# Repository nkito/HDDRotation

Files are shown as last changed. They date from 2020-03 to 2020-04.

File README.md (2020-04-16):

# HDDRotation - illumination utilizing HDD rotation.

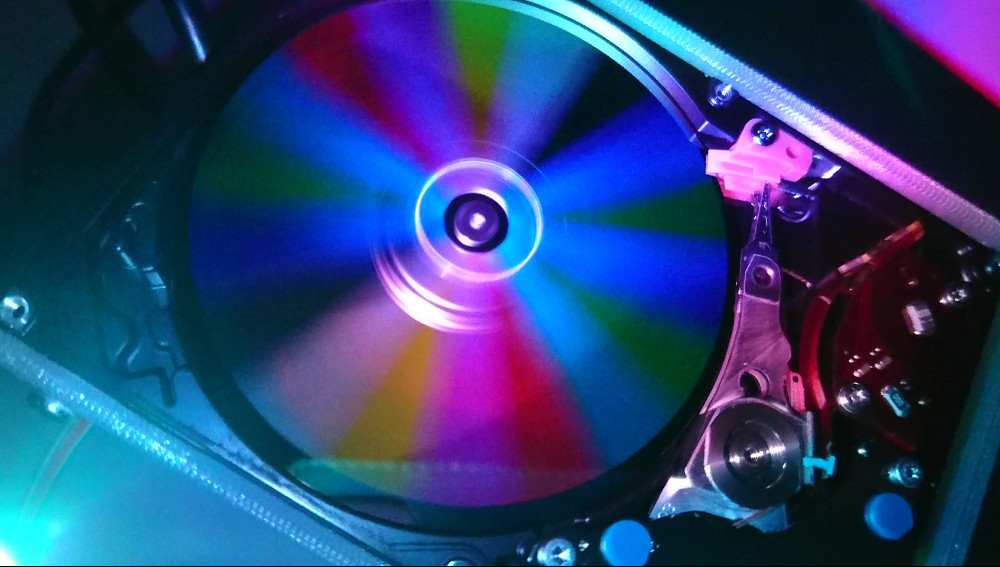
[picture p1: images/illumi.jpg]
illumination


## Overview

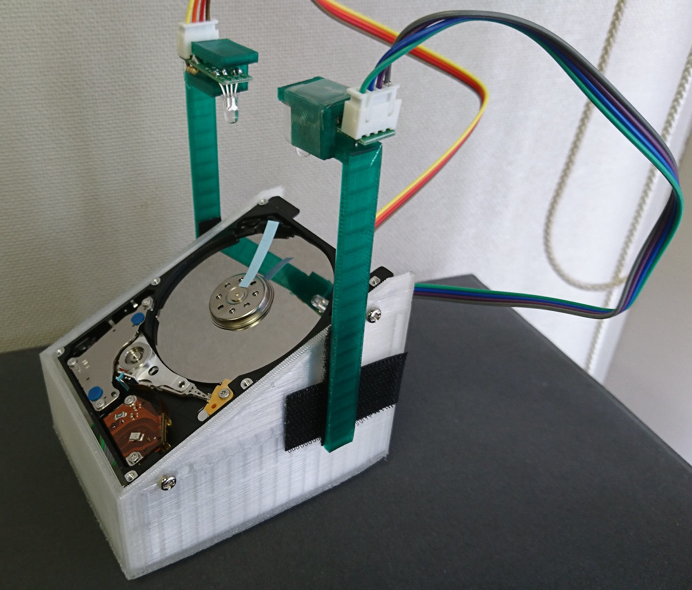
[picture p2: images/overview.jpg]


## Operating principle

The light from the LEDs illuminates the strip of post-it.
The rotation of the strip and the light from the LEDs are synchronized.
In other words, the color of the LEDs varies depending on the position of the strip.
Stable images are observed due to the characteristics of the human eye.

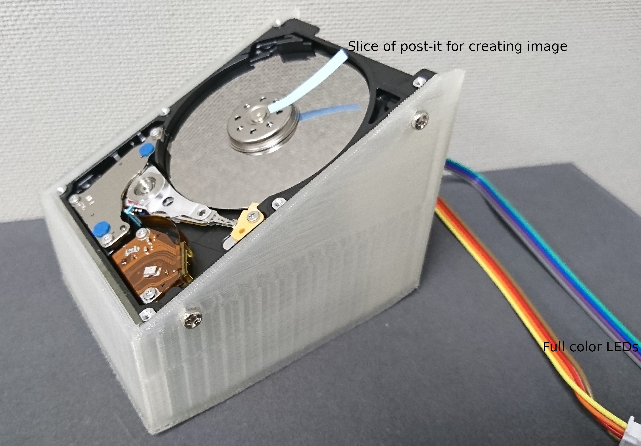
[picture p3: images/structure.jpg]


## Hardware

### Parts

* 2.5-inch HDD
* Arduino Uno
* Transistor Array 2003A (such as TD62003APG(Toshiba), ULN2003AN(TI))
* Full color LEDs
* Some resistors
* Case printed out with a 3D printer
* Screws (M3)

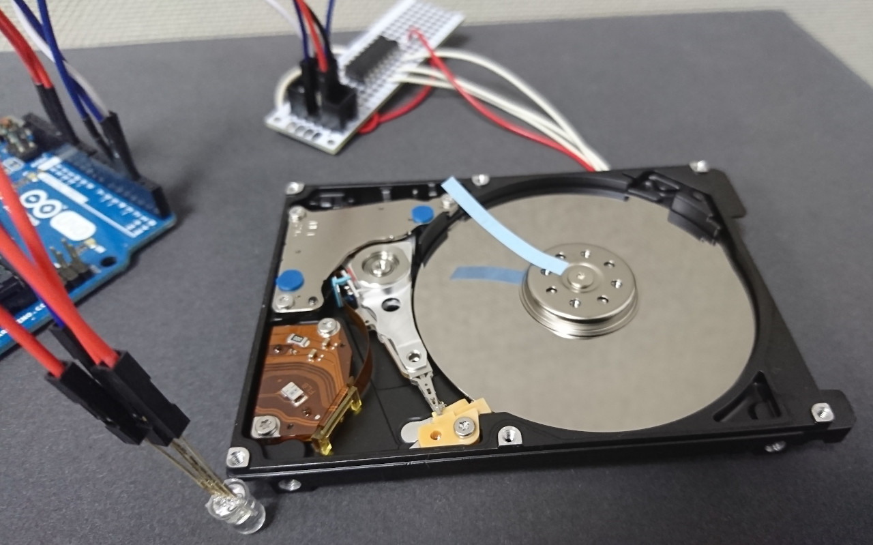
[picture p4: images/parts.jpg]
parts


### Schematic 

Schematic 

### Case

Case

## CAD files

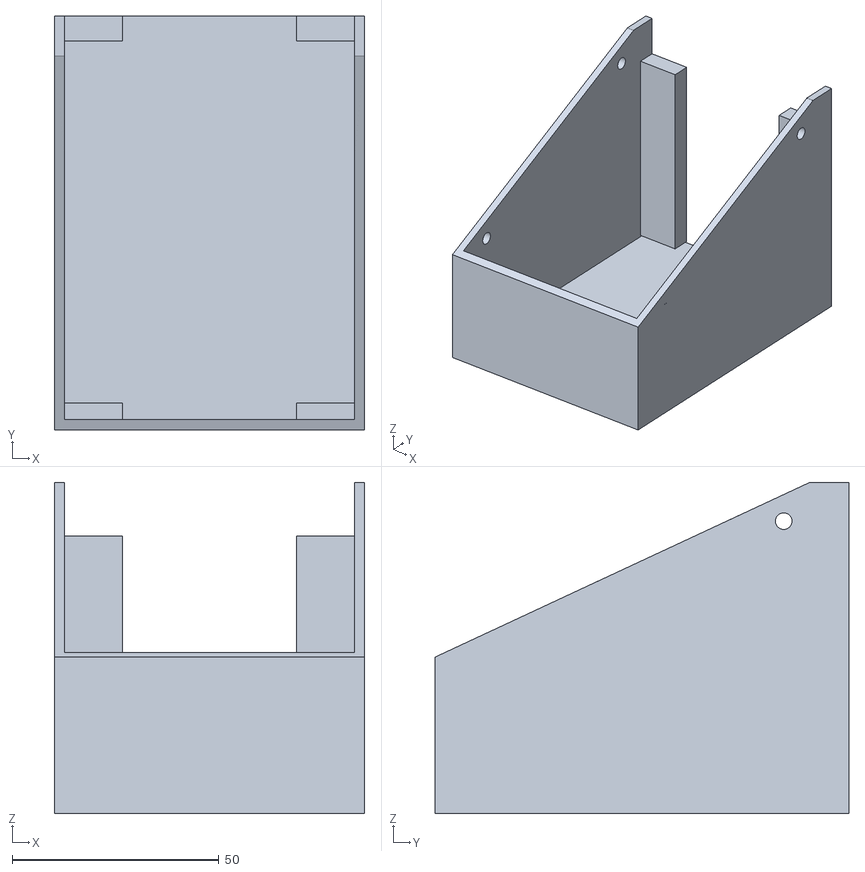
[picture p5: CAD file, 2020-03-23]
3DModel/HDDcase.stl
75.0 x 100.0 x 80.0

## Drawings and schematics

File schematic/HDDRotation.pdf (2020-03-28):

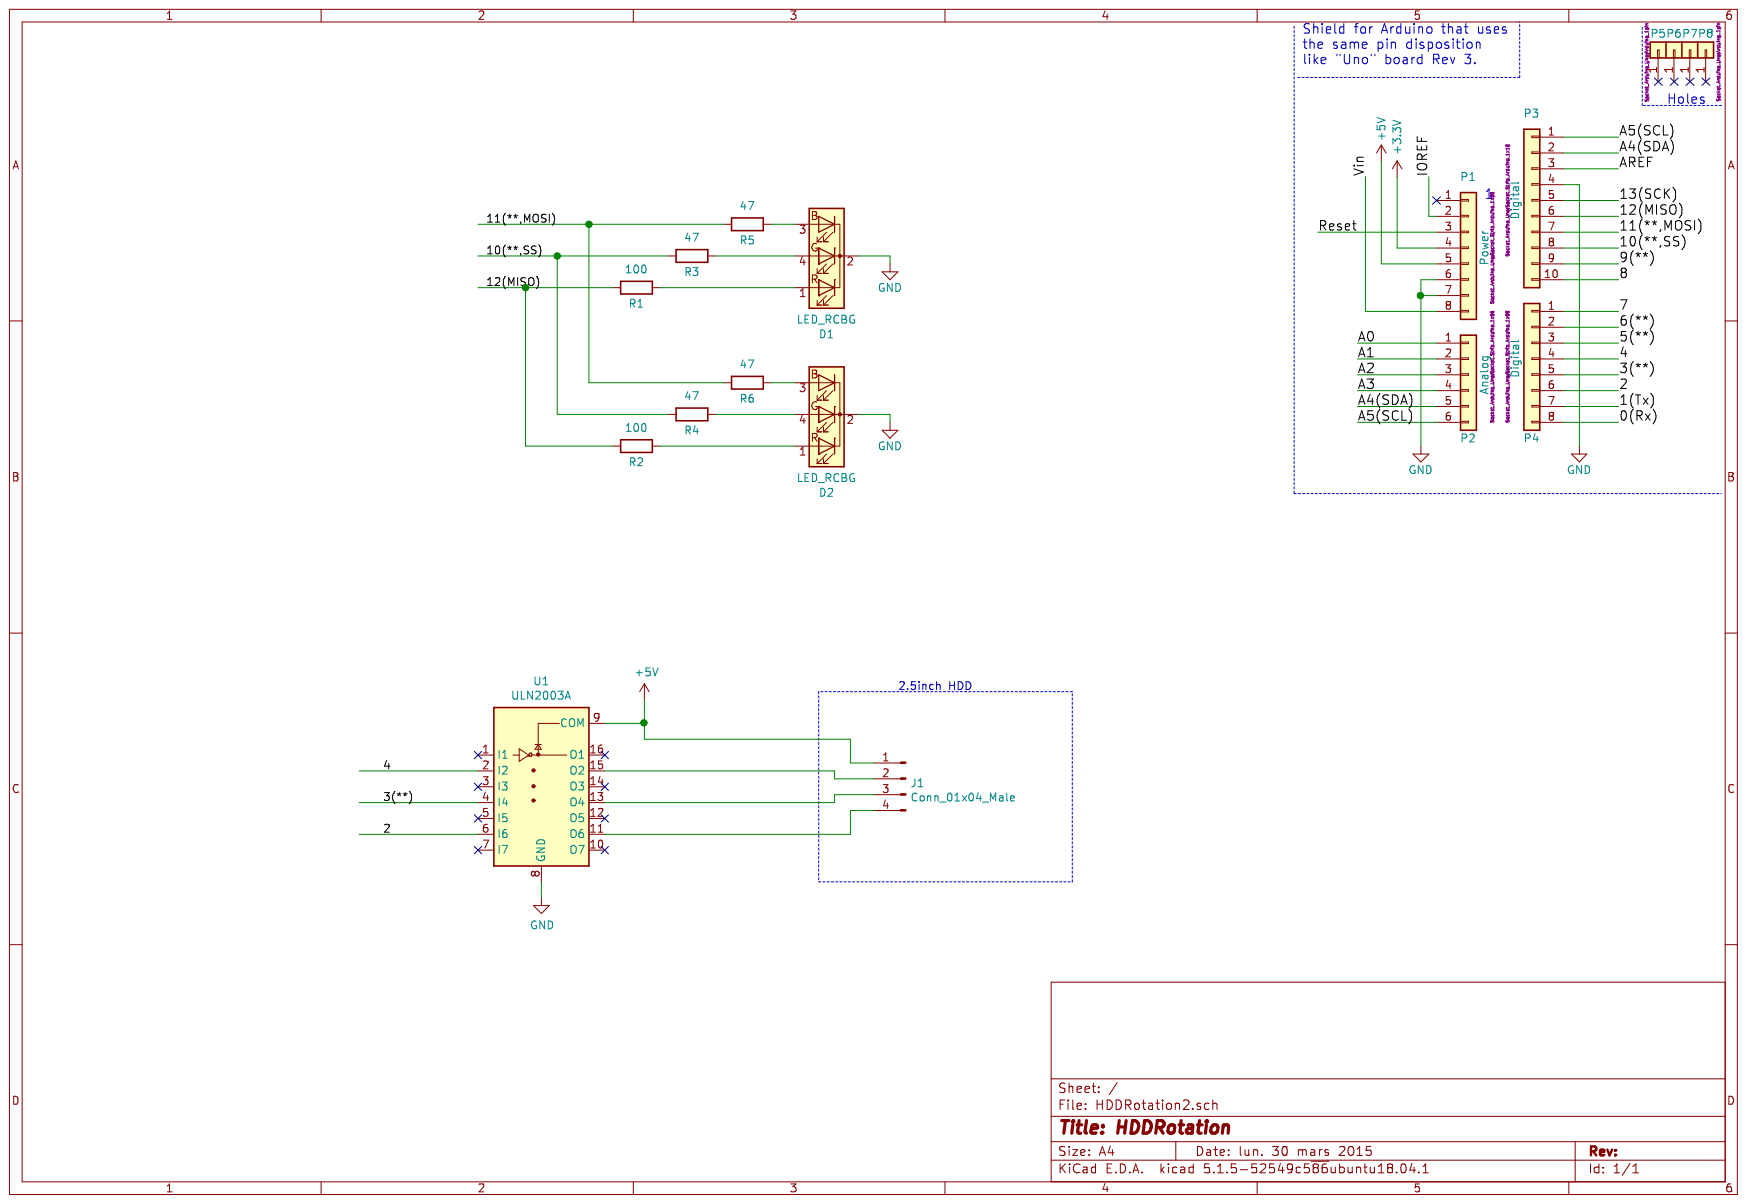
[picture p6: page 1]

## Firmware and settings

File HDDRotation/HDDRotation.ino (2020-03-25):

// HDD Rotation program 

// Definition of pins
const int MOTOR_1   = 2;
const int MOTOR_2   = 3;
const int MOTOR_3   = 4;

const int LED_BOARD = 13;
const int LED_R     = 12;
const int LED_G     = 10;
const int LED_B     = 11;


// delay for controlling the motor [micro seconds]
const int start_delay  = 30000;  // initial delay
const int stable_delay = 800;    // target delay (minimum delay is 800 in my experiment)

void setup() {
  pinMode(MOTOR_1, OUTPUT);
  pinMode(MOTOR_2, OUTPUT);
  pinMode(MOTOR_3, OUTPUT);

  pinMode(LED_R    , OUTPUT);
  pinMode(LED_G    , OUTPUT);
  pinMode(LED_B    , OUTPUT);
  pinMode(LED_BOARD, OUTPUT);
  
  digitalWrite( MOTOR_1,  LOW);
  digitalWrite( MOTOR_2,  LOW);
  digitalWrite( MOTOR_3,  LOW);

  digitalWrite(     LED_R, LOW);
  digitalWrite(     LED_G, LOW);
  digitalWrite(     LED_B, LOW);
  digitalWrite( LED_BOARD, LOW);
}



void motorctl(int rot){
  switch(rot){
   case 1:
    digitalWrite( MOTOR_1, HIGH);
    digitalWrite( MOTOR_2,  LOW);
    digitalWrite( MOTOR_3,  LOW);
    break;
   case 2:
    digitalWrite( MOTOR_1,  LOW);
    digitalWrite( MOTOR_2, HIGH);
    digitalWrite( MOTOR_3,  LOW);
    break;
   default:
    digitalWrite( MOTOR_1,  LOW);
    digitalWrite( MOTOR_2,  LOW);
    digitalWrite( MOTOR_3, HIGH);
  }
}
void ledctl(int col){
  digitalWrite( LED_R, (col&0x4) ? HIGH : LOW );
  digitalWrite( LED_G, (col&0x2) ? HIGH : LOW );
  digitalWrite( LED_B, (col&0x1) ? HIGH : LOW);
}


void spinup(void){
  int s = start_delay; // delay in micro seconds
  int d;               // delay in [ms]
  int i;

  do{
    d = s/1000;
    for(i=1; i<=3; i++){
      motorctl(i);
      if( d < 10 ){
        delayMicroseconds(s);
      }else{
        delay(d);
      }
    }
    if(s >10000){
      s = s - 1000;
    }else if(s > 5000){
      s = s - 100;
    }else if(s > 2000){
      s = s - 10;
    }else{
      s = s - 1;
    }
  }while( s > stable_delay );
}

void stable_rot1(int d, int count){
  int i, t;
  unsigned long start = 0, current;
  
  while(1){
    current = millis();
    if(start == 0) start = current;
    
    t = (current - start) / d;
    
    for(i=0; i<3*6; i++){
      motorctl((i%3)+1);
      delayMicroseconds(stable_delay);
      ledctl(i + t);
    }
    if( t == count ){
      return;
    }
  }
}

void stable_rot2(int fgcolor, int bgcolor, int d, int count){
  int i, rad, loop = 0;
  unsigned long start = 0, current;

  while(1){
    current = millis();
    if( start == 0 ) start = current;

    rad = (current - start) / d;
    
    for(i=0; i<3*6; i++){
      motorctl((i%3)+1);
      delayMicroseconds(stable_delay);
      ledctl( (i < rad) ? fgcolor : bgcolor );
    }
    if(rad > 3*6){
      if(++loop >= count){
        return;
      }
      start = current;
      i = fgcolor;
      fgcolor = bgcolor;
      bgcolor = i;
    }
  }
}

void loop() {
  int color=1;

  spinup();

  while(1){
    stable_rot1(250, 18);
    stable_rot2(color, 0, 50, 4);
    if( ++color == 8 ){ color = 1; }
  }
  
}
